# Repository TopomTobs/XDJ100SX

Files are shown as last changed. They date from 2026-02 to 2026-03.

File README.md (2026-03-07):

# XDJ100SX
An Open Source Standalone DJ Deck

This project is another experimental project that combines hardware, MIDI and open source software to convert an old Pioneer CDJ-100S to a standalone player using all modern features.

XDJ100SX

## Main Requirements:

- Raspberri Pi 3b+
- Arduino/Teensy with MIDI libraries or RaspberryPi Pico 2

## Content:

- /arduino/ -> firmware code
- /datasheets/ -> Original CDJ, Teensy and Raspberry datasheets
- /images/ -> Process and result pics
- /mixxx/ -> Custom skin and MIDI mapping for this project
- /print-assets/ -> STL file to 3D print + adhesive custom skin to print
- /docs/ -> Documentation of this project

## Raspberri Pi 3B+ Image file

Note it only works with the Raspberry Pi 3B+

[Image File](https://drive.google.com/file/d/1xF3MYwbI78TJTnMUjNkVMXjbA1-jqFb2/view?usp=sharing).

+ New Image File with DAC Configured

[compressed Image File by TopomTobs](https://1drv.ms/u/c/e532e1f91932269c/IQD9aWiq7WFSToYP2p__aJ3PAWQDYGNdWBTJ3ya3zKkWz0E?e=H8lEBm).

### 📜 License
- All code in this repository is released under the [GNU GPL v3 License](https://www.gnu.org/licenses/gpl-3.0.html).
- All documentation, 3D models, and visual materials are released under the [Creative Commons BY-SA 4.0 License](https://creativecommons.org/licenses/by-sa/4.0/).

2025 Marc Monka

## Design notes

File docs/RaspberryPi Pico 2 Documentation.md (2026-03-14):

# Introduction
This Build documentation should be a rebuild guide to enable everyone to rebuild the XDJ100sx. The Player build in this guide is a derivative from the original, it should work the same but changes are made internally. For example the micro-controller used in the original, is now [difficult to get](https://www.pjrc.com/store/teensylc.html), was replaced with the RaspberryPi Pico 2. An important addition to the original is the proper DAC used. 

## What do you need to build this one
#### Materials
+ CDJ100s
+ RaspberryPi 3b+
+ RaspberryPi Pico 2
+ DAC Plus or Pro (depending on if you need balanced audio) or any other good DAC
+ 5 inch touch Display
+ Rotary Encoder (KY-040)
+ USB-Port (Female)
+ 5V Power-Supply
+ Some cables(USB 2.0, audio, simple one strand)
+ Soldering stuff
#### Appliances
+ Soldering Iron
+ Multimeter (useful for debugging)
+ 3D Printer

# Building
## Dissembling XDJ100s
We only need the Housing and the PCB with the buttons and leds, optionally you could keep the power-supply PCB for the cinch output and on-off button.
You should be left with this:

## Button PCB
### Cutting traces and laying new Ground
We will have to cut some traces on the PCB first and then lay a new Ground. All input and output on this PCB share the same ground. The red lines are where you have to cut the PCB. The green marks indicate a bridge where for example a resistor was and the traces need to be connected (This is the case where led are). Check with a multimeter if every button and led is connected together via Ground. To Check if all Traces have been cut correctly one may use the debug code with Serial Monitor Output when a button is pressed (Arduino/Pico2/Debug just flash and check the Serial Monitor). 



## Wiring Buttons to Pico 2

| Button | Pin on Pico |
| --- | --- |
| eject | 0 |
| track previous | 1 |
| track next | 2 |
| search back | 3 |
| search next | 4 |
| cue | 5 |
| jet | 6 |
| play | 7 |
| zip | 8 |
| wah | 9 |
| hold | 10 |
| time | 11 |
| mastertempo | 12 |
| jog A | 14 |
| jog B | 15 |
| Browse A | 16 |
| Browse B | 17 |
| load | 18 |
| led cue | 19 |
| led Play | 20 |
| led Intern | 21 |
| led CD | 22 |
| pitch | A0 |



### Wiring Jog
I use 10k Ohm Resistors as pullups. It should also be possible with Pico onboard Pullups but I am not quite sure with that (Improvements are to be made here).

### Wiring Browser
Yellow = 18
Blue = 17
Brown = 16

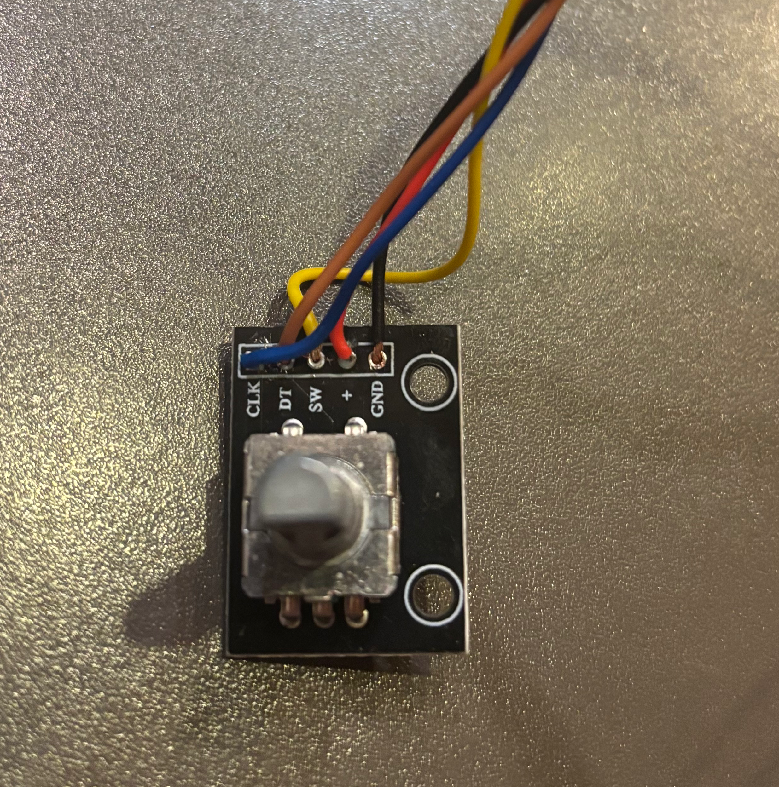
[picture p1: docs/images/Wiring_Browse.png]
Wiring_Browse


### USB PICO 2 to Raspberry

# Changes to the Linux envirement
The file in /home/xdj100sx/.mixxx/controllers/XDJ100SX.midi.xml have to be replaced with the Pico Midi mappings. (See mixxx/MIDI/RaspberryPi_Pico2 on Github) Also make sure you use the right file in the mixxx settings. (Options/Preferences/Controllers/NameofController Load Mapping: PICO2_MIDI_Mapping_File).
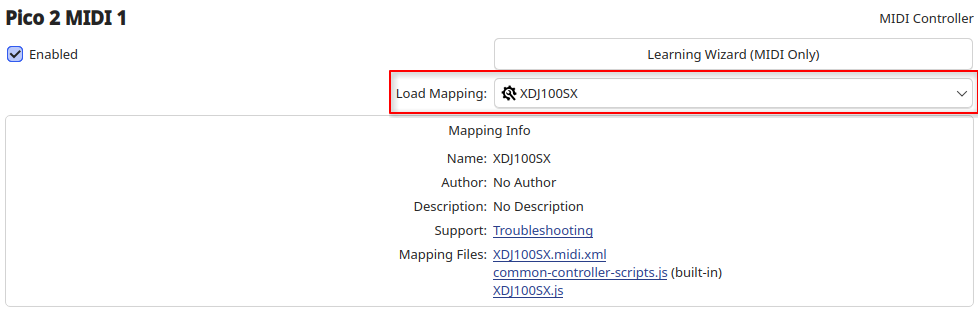
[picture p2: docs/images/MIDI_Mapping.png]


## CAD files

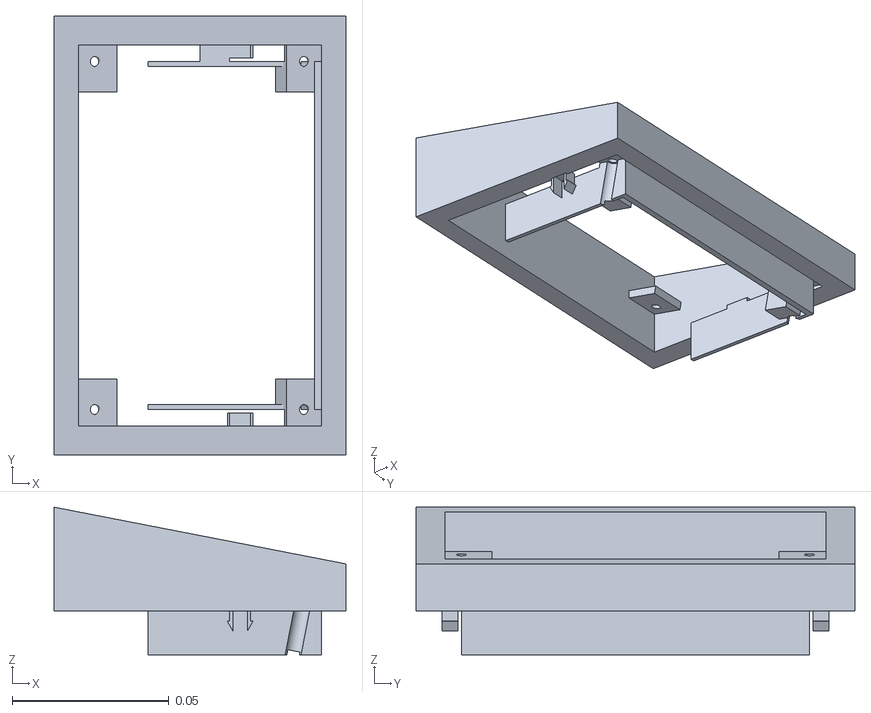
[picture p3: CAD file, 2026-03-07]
print-assets/XDJ100sx_V6.stl
0.093 x 0.14 x 0.0471

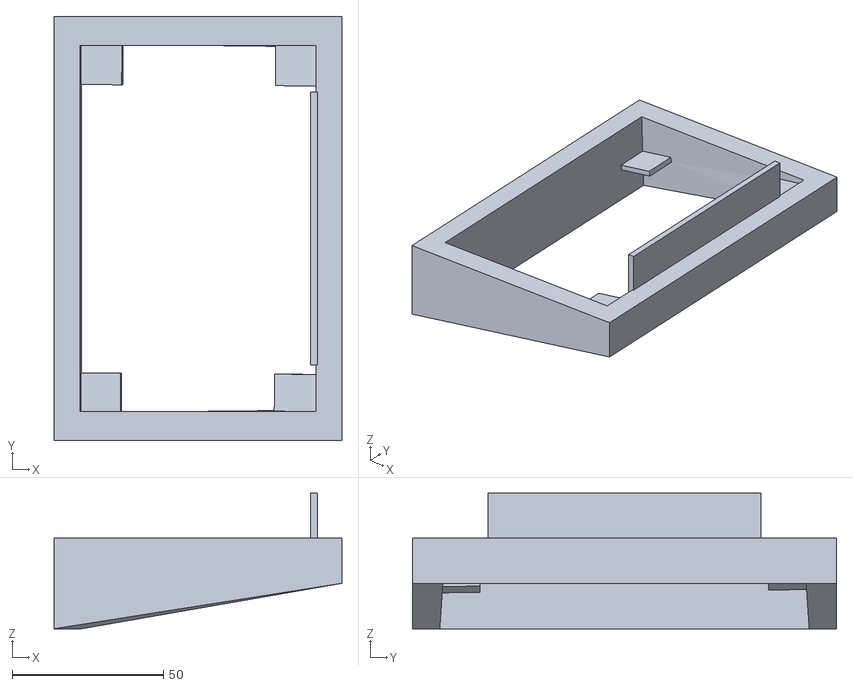
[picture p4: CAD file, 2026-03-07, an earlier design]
print-assets/Old/xdj100sx_3dprintstl.stl
95.0 x 140.0 x 44.8

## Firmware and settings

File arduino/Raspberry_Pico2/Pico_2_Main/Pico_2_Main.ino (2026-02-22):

/*
This Code is made for the Raspberrypi pico 2
It is pretty much the same as the code for the teensy certain libraries do not work on the raspberrypi pico 2 due to missing interupt pins these libraries have been changed. 

!The pinout differs from the original!
Also some midi code have changed (LEDs) there are no more overlapping midi code between incomming and outgoing messages. This has made some issues on my testbench
*/

#include <Bounce2.h>
#include <Adafruit_TinyUSB.h>
#include <MIDI.h>
#include <ResponsiveAnalogRead.h>
#include <elapsedMillis.h>
#include "PicoEncoder.h"
#include "pio_encoder.h"
#include "Arduino.h"

Adafruit_USBD_MIDI usbMIDI;
MIDI_CREATE_INSTANCE(Adafruit_USBD_MIDI, usbMIDI, MIDI);
const int eject_pin = 0;
const int track_previous_pin = 1;
const int track_next_pin = 2;
const int search_back_pin = 3;
const int search_forward_pin = 4;
const int cue_pin = 5;
const int play_pin = 7;
const int jet_pin = 6;
const int zip_pin = 8;
const int wah_pin = 9;
const int hold_pin = 10;
const int time_pin = 11;
const int mastertempo_pin = 12;

//LEDs
const int ledCue = 19;
const int ledPlay = 20;
const int ledIntern = 21;
const int ledCd = 22;

//pitch
const int pitchPin = A0;
ResponsiveAnalogRead analog(pitchPin, true);
int lastMSB = -1;
int lastLSB = -1;


//jogwheel
const int jogA_pin = 14;
const int jogB_pin = 15;
const int midiChannel = 2;
const int jogControlNumber = 20;
PioEncoder jog(jogA_pin);
long lastPosition_jog = 0;

//Browse
const int browseA_pin = 16;
const int browseB_pin = 17;
const int load_pin = 18;
const int midiChannelb = 3;
const int DEBOUNCE_MS = 3;  
const int NOTE_SCROLL_DOWN = 70;
const int NOTE_SCROLL_UP = 71;
elapsedMillis debounceTime_browse;  // Temps per filtrar rebots browse¡
PioEncoder browse(browseA_pin);
long lastPosition_browse = 0;


//Debounce of Button
Bounce2::Button cue_Button = Bounce2::Button();
Bounce2::Button play_Button = Bounce2::Button();
Bounce2::Button eject_Button = Bounce2::Button();
Bounce2::Button track_previous_Button = Bounce2::Button();
Bounce2::Button track_next_Button = Bounce2::Button();
Bounce2::Button search_back_Button = Bounce2::Button();
Bounce2::Button search_forward_Button = Bounce2::Button();
Bounce2::Button jet_Button = Bounce2::Button();
Bounce2::Button zip_Button = Bounce2::Button();
Bounce2::Button wah_Button = Bounce2::Button();
Bounce2::Button hold_Button = Bounce2::Button();
Bounce2::Button time_Button = Bounce2::Button();
Bounce2::Button mastertempo_Button = Bounce2::Button();
Bounce2::Button load_Button = Bounce2::Button();
const int channel = 1;

//Notes for incomming midi messages !Not the same as on the original!
const int PLAY_NOTE_INDICATOR = 0x4E;
const int CUE_NOTE_INDICATOR = 0x4c;
const int LEDINTERN_NOTE_INDICATOR = 0x4d;
const int LEDCD_NOTE_INDICATOR = 0x4b;
const int SIESTAPLAY_NOTE_INDICATOR = 0x4a;
bool siestaplay = false;

//LED parameter
bool parpadeig = false;
unsigned long tempsAnterior = 0;



//Handler for LEDs like Play and Cue button to light up
void handleNoteOn(byte channel, byte note, byte velocity) {
  // Comprovem si la nota rebuda és la del nostre indicador de Play
  if (note == PLAY_NOTE_INDICATOR) {
    // Si la velocitat és més gran que 0, vol dir "Play", així que encenem el LED
    if (velocity > 0) {
      digitalWrite(ledPlay, HIGH);

    }
    // Si la velocitat és 0, es tracta com un Note Off, així que l'apaguem
    else {
      digitalWrite(ledPlay, LOW);
    }
  }
  if (note == CUE_NOTE_INDICATOR) {
    // Si la velocitat és més gran que 0, vol dir "Play", així que encenem el LED
    if (velocity > 0) {
      digitalWrite(ledCue, HIGH);
    }
    // Si la velocitat és 0, es tracta com un Note Off, així que l'apaguem
    else {
      digitalWrite(ledCue, LOW);
    }
  }
  //LED INTERN MARCA EL BPM, NOMÉS SI ESTÀ EN PLAY
  if (note == SIESTAPLAY_NOTE_INDICATOR) {
    siestaplay = true;
  }
  if (note == LEDINTERN_NOTE_INDICATOR && siestaplay == true) {
    digitalWrite(ledIntern, HIGH);
  }
  //LED CD el farem parpadejar quan rebi informació que la cançó s'està acabant (mixxx envia 1)
  if (note == LEDCD_NOTE_INDICATOR) {
    parpadeig = (velocity > 0);
  }
}


// Turns LEDs off 
void handleNoteOff(byte channel, byte note, byte velocity) {
  // Comprovem si la nota rebuda és la del nostre indicador de Play
  if (note == PLAY_NOTE_INDICATOR) {
    // Si rebem un Note Off per a aquesta nota, apaguem el LED
    digitalWrite(ledPlay, LOW);
  }
  if (note == CUE_NOTE_INDICATOR) {
    // Si rebem un Note Off per a aquesta nota, apaguem el LED
    digitalWrite(ledCue, LOW);
  }

  if (note == LEDCD_NOTE_INDICATOR) {
    parpadeig = false;
  }

  if (note == SIESTAPLAY_NOTE_INDICATOR) {
    siestaplay = false;
  }
  if (note == LEDINTERN_NOTE_INDICATOR || siestaplay == false) {
    digitalWrite(ledIntern, LOW);
  }
}

// Initializing debouncing of Buttons
void setupBounce(Bounce2::Button &button, int Pin) {
  button.attach(Pin, INPUT_PULLUP);
  button.interval(10);
  button.setPressedState(HIGH);
}

void setup() {
  usbMIDI.begin(0);

  MIDI.setHandleNoteOn(handleNoteOn);
  MIDI.setHandleNoteOff(handleNoteOff);

  setupBounce(play_Button, play_pin);
  setupBounce(cue_Button, cue_pin);
  setupBounce(eject_Button, eject_pin);
  setupBounce(track_previous_Button, track_previous_pin);
  setupBounce(track_next_Button, track_next_pin);
  setupBounce(search_back_Button, search_back_pin);
  setupBounce(search_forward_Button, search_forward_pin);
  setupBounce(jet_Button, jet_pin);
  setupBounce(zip_Button, zip_pin);
  setupBounce(wah_Button, wah_pin);
  setupBounce(hold_Button, hold_pin);
  setupBounce(time_Button, time_pin);
  setupBounce(mastertempo_Button, mastertempo_pin);
  setupBounce(load_Button, load_pin);

  pinMode(ledCue, OUTPUT);
  pinMode(ledPlay, OUTPUT);
  pinMode(ledIntern, OUTPUT);
  pinMode(ledCd, OUTPUT);
  pinMode(25, OUTPUT);
  digitalWrite(25, HIGH);

  jog.begin();
  browse.begin();
}
// Decodes Jogwheel
void jogread() {
  long newPosition_jog = jog.getCount();
  if (newPosition_jog % 4 == 0 && newPosition_jog != lastPosition_jog) {
    if (newPosition_jog > lastPosition_jog) {
      MIDI.sendControlChange(jogControlNumber, 65, midiChannel);
    } else {
      MIDI.sendControlChange(jogControlNumber, 63, midiChannel);
    }
    lastPosition_jog = newPosition_jog;
  }
}

// This method decodes the Browse only the rotation is handled here for the Load knob have a look at the other knobs
void browseread() {
  long newPosition_browse = browse.getCount();
  long delta_browse = newPosition_browse - lastPosition_browse;

  if (debounceTime_browse > DEBOUNCE_MS && delta_browse != 0) {
    if (newPosition_browse % 4 == 0 && newPosition_browse != lastPosition_browse) {

      if (newPosition_browse > lastPosition_browse) {
        // Direcció: DRETA (baixar a la llista)
        MIDI.sendNoteOn(NOTE_SCROLL_DOWN, 127, midiChannelb);
        MIDI.sendNoteOff(NOTE_SCROLL_DOWN, 0, midiChannelb);

      } else {
        MIDI.sendNoteOn(NOTE_SCROLL_UP, 127, midiChannelb);
        MIDI.sendNoteOff(NOTE_SCROLL_UP, 0, midiChannelb);
      }   
      lastPosition_browse = newPosition_browse;
    }
  }
}


void updateButtons() {
  cue_Button.update();
  play_Button.update();
  eject_Button.update();
  track_previous_Button.update();
  track_next_Button.update();
  search_back_Button.update();
  search_forward_Button.update();
  jet_Button.update();
  zip_Button.update();
  wah_Button.update();
  hold_Button.update();
  time_Button.update();
  mastertempo_Button.update();
  load_Button.update();

  while (!TinyUSBDevice.mounted()) delay(1);
}

void loop() {
  updateButtons();

//Button triggering
  //Play
  if (play_Button.released()) {
    MIDI.sendNoteOn(60, 127, channel);
  } else if (play_Button.pressed()) {
    MIDI.sendNoteOn(60, 0, channel);
  }

  //cue
  if (cue_Button.released()) {
    MIDI.sendNoteOn(61, 127, channel);
  } else if (cue_Button.pressed()) {
    MIDI.sendNoteOn(61, 0, channel);
  }

  //mastertempo
  if (mastertempo_Button.released()) {
    MIDI.sendNoteOn(62, 127, channel);
  } else if (mastertempo_Button.pressed()) {
    MIDI.sendNoteOn(62, 0, channel);
  }

  //Eject
  if (eject_Button.released()) {
    MIDI.sendNoteOn(63, 127, channel);
  } else if (eject_Button.pressed()) {
    MIDI.sendNoteOn(63, 0, channel);
  }

  //trackprev
  if (track_previous_Button.released()) {
    MIDI.sendNoteOn(64, 127, channel);
  } else if (track_previous_Button.pressed()) {
    MIDI.sendNoteOn(64, 0, channel);
  }

  //nextTrack
  if (track_next_Button.released()) {
    MIDI.sendNoteOn(65, 127, channel);
  } else if (track_next_Button.pressed()) {
    MIDI.sendNoteOn(65, 0, channel);
  }

  //searchback
  if (search_back_Button.released()) {
    MIDI.sendNoteOn(66, 127, channel);
  } else if (search_back_Button.pressed()) {
    MIDI.sendNoteOn(66, 0, channel);
  }

  //searchforward
  if (search_forward_Button.released()) {
    MIDI.sendNoteOn(67, 127, channel);
  } else if (search_forward_Button.pressed()) {
    MIDI.sendNoteOn(67, 0, channel);
  }

  //jet
  if (jet_Button.released()) {
    MIDI.sendNoteOn(68, 127, channel);
  } else if (jet_Button.pressed()) {
    MIDI.sendNoteOn(68, 0, channel);
  }

  //zip
  if (zip_Button.released()) {
    MIDI.sendNoteOn(69, 127, channel);
  } else if (zip_Button.pressed()) {
    MIDI.sendNoteOn(69, 0, channel);
  }

  //wah
  if (wah_Button.released()) {
    MIDI.sendNoteOn(70, 127, channel);
  } else if (wah_Button.pressed()) {
    MIDI.sendNoteOn(70, 0, channel);
  }

  //hold
  if (hold_Button.released()) {
    MIDI.sendNoteOn(71, 127, channel);
  } else if (hold_Button.pressed()) {
    MIDI.sendNoteOn(71, 0, channel);
  }

  //time
  if (time_Button.released()) {
    MIDI.sendNoteOn(72, 127, channel);
  } else if (time_Button.pressed()) {
    MIDI.sendNoteOn(72, 0, channel);
  }

  //load
  if (load_Button.released()) {
    MIDI.sendNoteOn(73, 127, channel);
  } else if (load_Button.pressed()) {
    MIDI.sendNoteOn(73, 0, channel);
  }


  //pitch
  analog.update();
  int raw = analog.getValue();  // valor ja suavitzat

  int value14 = map(raw, 0, 1023, 0, 16383);

  byte msb = (value14 >> 7) & 0x7F;
  byte lsb = value14 & 0x7F;


  if (msb != lastMSB) {
    MIDI.sendControlChange(0, msb, 1);
    lastMSB = msb;
  }

  if (lsb != lastLSB) {
    MIDI.sendControlChange(32, lsb, 1);
    lastLSB = lsb;
  }

  //jog
  jogread();
  browseread();
  if (parpadeig) {
    if (millis() - tempsAnterior >= 1000) {
      tempsAnterior = millis();
      digitalWrite(ledCd, !digitalRead(ledCd));
    }
  } else {
    digitalWrite(ledCd, LOW);
  }


// Read incomming midi messages
  while (MIDI.read()) {}
}

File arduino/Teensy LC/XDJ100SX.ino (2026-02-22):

#include <Bounce2.h>
#include "PicoEncoder.h"
#include <elapsedMillis.h>
#include <ResponsiveAnalogRead.h>


// MIDI IN - botons
const int eject_pin = 0;
const int track_previous_pin = 1;
const int track_next_pin = 2;
const int search_back_pin = 3;
const int search_forward_pin = 4;
const int cue_pin = 5;
const int play_pin = 6;
const int jet_pin = 7;
const int zip_pin = 8;
const int wah_pin = 9;
const int hold_pin = 10;
const int time_pin = 11;
const int mastertempo_pin = 12;

//encoder jog
const int jogA_pin = 20;
const int jogB_pin = 15;
const int midiChannel = 2;
const int jogControlNumber = 20;
Encoder jog(jogA_pin, jogB_pin);
long lastPosition_jog = 0;



//encoder browser
const int browseA_pin = 22;
const int browseB_pin = 21;
const int load_pin= 23;
const int midiChannelb = 3;
const int DEBOUNCE_MS = 3;    // Debounce curt
const int NOTE_SCROLL_DOWN = 70;
const int NOTE_SCROLL_UP = 71;
elapsedMillis debounceTime_browse;  // Temps per filtrar rebots browse¡
Encoder browse(browseA_pin, browseB_pin);
long lastPosition_browse = 0;       // Última posició llegida

elapsedMillis msec = 0;


/* Pitch slider old
const int pitch_pin = A0;
const int channel_pitch = 3;
const int controllerA0 = 7;
int previousA0 = -1;
ResponsiveAnalogRead analog(pitch_pin, true);
*/


//Pitch new

const int pitchPin = A0;
ResponsiveAnalogRead analog(pitchPin, true);
int lastMSB = -1;
int lastLSB = -1;



// MIDI OUT - Leds

const int ledCue = 16;
const int ledPlay = 17;
const int ledIntern = 18;
const int ledCd = 19;

// Canals MIDI
const  int channel = 1;

//Notes que rebo de Mixxx pel play, cue, etc
const int PLAY_NOTE_INDICATOR = 61;
const int CUE_NOTE_INDICATOR = 62;
const int LEDINTERN_NOTE_INDICATOR = 63;
const int LEDCD_NOTE_INDICATOR = 64;
const int SIESTAPLAY_NOTE_INDICATOR = 65;
bool siestaplay = false;

//Parpadeig final de track
bool parpadeig = false;
unsigned long tempsAnterior = 0;



//Bounce botons cada 5ms
Bounce eject_boto = Bounce (eject_pin, 50);
Bounce trackprevious_boto = Bounce (track_previous_pin, 50);
Bounce track_next_boto = Bounce (track_next_pin, 50);
Bounce search_back_boto = Bounce (search_back_pin, 50);
Bounce search_forward_boto = Bounce (search_forward_pin, 50);
Bounce play_boto = Bounce (play_pin, 50);
Bounce cue_boto = Bounce (cue_pin, 50);
Bounce jet_boto = Bounce (jet_pin, 50);
Bounce zip_boto = Bounce (zip_pin, 50);
Bounce wah_boto = Bounce (wah_pin, 50);
Bounce hold_boto = Bounce (hold_pin, 50);
Bounce time_boto = Bounce (time_pin, 50);
Bounce mastertempo_boto = Bounce (mastertempo_pin, 50);
Bounce load_boto = Bounce (load_pin, 50);




// --- FUNCIONS QUE S'EXECUtEN QUAN ES REP UN MISSATGE MIDI ---


// Aquesta funció s'executarà automàticament quan es rebi un "Note On"
void handleNoteOn(byte channel, byte note, byte velocity) {
 // Comprovem si la nota rebuda és la del nostre indicador de Play
 if (note == PLAY_NOTE_INDICATOR) {
   // Si la velocitat és més gran que 0, vol dir "Play", així que encenem el LED
   if (velocity > 0) {
     digitalWrite(ledPlay, HIGH);
   }
   // Si la velocitat és 0, es tracta com un Note Off, així que l'apaguem
   else {
     digitalWrite(ledPlay, LOW);
   }
 }
 if (note == CUE_NOTE_INDICATOR) {
   // Si la velocitat és més gran que 0, vol dir "Play", així que encenem el LED
   if (velocity > 0) {
     digitalWrite(ledCue, HIGH);
   }
   // Si la velocitat és 0, es tracta com un Note Off, així que l'apaguem
   else {
     digitalWrite(ledCue, LOW);
   }
 }
//LED INTERN MARCA EL BPM, NOMÉS SI ESTÀ EN PLAY
if(note == SIESTAPLAY_NOTE_INDICATOR){
  siestaplay = true;
}
if (note == LEDINTERN_NOTE_INDICATOR && siestaplay == true)
{
  digitalWrite(ledIntern, HIGH);
} 
 //LED CD el farem parpadejar quan rebi informació que la cançó s'està acabant (mixxx envia 1)
 if (note == LEDCD_NOTE_INDICATOR) {
    parpadeig = (velocity > 0);
    }

    
}


// Aquesta funció s'executarà automàticament quan es rebi un "Note Off"
void handleNoteOff(byte channel, byte note, byte velocity) {
 // Comprovem si la nota rebuda és la del nostre indicador de Play
 if (note == PLAY_NOTE_INDICATOR) {
   // Si rebem un Note Off per a aquesta nota, apaguem el LED
   digitalWrite(ledPlay, LOW);
 }
 if (note == CUE_NOTE_INDICATOR) {
   // Si rebem un Note Off per a aquesta nota, apaguem el LED
   digitalWrite(ledCue, LOW);
 }
 
 if (note == LEDCD_NOTE_INDICATOR) {
   parpadeig = false;
 }

 if(note == SIESTAPLAY_NOTE_INDICATOR){
  siestaplay = false;
 }
 if (note == LEDINTERN_NOTE_INDICATOR || siestaplay == false){
  digitalWrite(ledIntern, LOW);
 }

}

void JogNudge(){
  long newPosition_jog = jog.read();
  
  if (newPosition_jog % 4 == 0 && newPosition_jog != lastPosition_jog) {
    if (newPosition_jog > lastPosition_jog) {
      // Dreta -> Envia 65
      usbMIDI.sendControlChange(jogControlNumber, 65, midiChannel);
    } else {
      // Esquerra -> Envia 63
      usbMIDI.sendControlChange(jogControlNumber, 63, midiChannel);
    }
    lastPosition_jog = newPosition_jog;
  }

}




void setup() {

pinMode(eject_pin, INPUT_PULLUP);
pinMode(track_previous_pin, INPUT_PULLUP);
pinMode(track_next_pin, INPUT_PULLUP);
pinMode(search_back_pin, INPUT_PULLUP);
pinMode(search_forward_pin, INPUT_PULLUP);
pinMode(cue_pin, INPUT_PULLUP);
pinMode(play_pin, INPUT_PULLUP);
pinMode(jet_pin, INPUT_PULLUP);
pinMode(eject_pin, INPUT_PULLUP);
pinMode(zip_pin, INPUT_PULLUP);
pinMode(wah_pin, INPUT_PULLUP);
pinMode(hold_pin, INPUT_PULLUP);
pinMode(time_pin, INPUT_PULLUP);
pinMode(mastertempo_pin, INPUT_PULLUP);
pinMode(load_pin, INPUT_PULLUP);


pinMode(ledCue, OUTPUT);
pinMode(ledPlay, OUTPUT);
pinMode(ledIntern, OUTPUT);
pinMode(ledCd, OUTPUT);

 // --- CONFIGURació MIDI ---
 // Assignem les nostres funcions "callback" als esdeveniments MIDI
 usbMIDI.setHandleNoteOn(handleNoteOn);
 usbMIDI.setHandleNoteOff(handleNoteOff);

 //Inicialitzo jog
 jog.write(0);

 //Inicialitzo browse
 browse.write(0);
 lastPosition_browse = 0;




}


void loop() {

eject_boto.update();
trackprevious_boto.update();
track_next_boto.update();
search_back_boto.update();
search_forward_boto.update();
cue_boto.update();
play_boto.update();
jet_boto.update();
zip_boto.update();
wah_boto.update();
hold_boto.update();
time_boto.update();
mastertempo_boto.update();
load_boto.update();


//Play
 if(play_boto.fallingEdge()){
   usbMIDI.sendNoteOn(60, 127, channel); 
 }
 if(play_boto.risingEdge()){
   usbMIDI.sendNoteOff(60, 0, channel); 
 }
 //CUE
 if(cue_boto.fallingEdge()){
   usbMIDI.sendNoteOn(61, 127, channel); 
 }
 if(cue_boto.risingEdge()){
   usbMIDI.sendNoteOff(61, 0, channel); 
 }


//Master Tempo
 if(mastertempo_boto.fallingEdge()){
   usbMIDI.sendNoteOn(62, 127, channel); 
 }
 if(mastertempo_boto.risingEdge()){
   usbMIDI.sendNoteOff(62, 0, channel); 
 }
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

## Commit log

2026-02-22 Added Support for Raspberry Pico 2
    This Adds code for the raspberry pico 2 it replaces some libraries from the original.
    [Pico_2_Main.ino, XDJ100SX.ino]
2026-02-22 Cleanup of Directory
    Added Teensy Folder for teensy code
2026-02-22 Added Mixx Midi mappings for Pico 2
    The Pico 2 build changed some Midi mappings. These changed Midi mappings are know in the updated File Directory under Pico 2
2026-03-07 Added some Files
    New Documentation for rebuilding. New 3D Print STL and more
    [XDJ100sx_V6.stl, xdj100sx_3dprintstl.stl]
2026-03-14 Update image links in Raspberry Pi Pico 2 documentation
2026-03-14 Added Browse Encoder pin connection
2026-03-14 Fix image syntax in Raspberry Pi Pico documentation
